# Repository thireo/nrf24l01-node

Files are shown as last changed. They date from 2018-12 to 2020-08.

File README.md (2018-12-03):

Indoor climate measuring nodes running on a single coin cell battery. Measurements done every 5 minutes (not necessarily sent at same interval).

Specs. for now:

* NRF24L01 - 2.4GHz module
* SAMD21G18 - MCU
* CR2450 - Coin cell battery ~ 500+mAh
* BME280 - Temperature, Humidity & Pressure.
* DS1302 - Ultra low power RTC for waking up node / Perhaps instead TLP5010.

Ideas to improve battery life:
Latch/flippydifloppy to control power to MCU + SIP32431.

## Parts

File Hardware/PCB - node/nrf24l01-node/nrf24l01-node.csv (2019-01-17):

Id | Designator | Package | Quantity | Designation | Supplier and ref
1 | REF**,REF** | MountingHole_4.3mm_M4---PASTY | 2 | MountingHole_4.3mm_M4---PASTY
2 | C19,C4,C18,C6,C7,C8,C9,C10,C11,C13,C15,C16,C17 | C_0603_1608Metric | 13 | 100nF
3 | IC4,IC3 | SC-70-6 | 2 | SIP32431
4 | R8 | R_0603_1608Metric | 1 | 1M
5 | R7,R4,R5,R6,R3 | R_0603_1608Metric | 5 | 100k
6 | BT1 | BatteryHolder_Keystone_3008_1x2450 | 1 | Coin Cell
7 | CON1 | HFW6R_2STE1LF | 1 | FPC_6POS
8 | L1 | C_0603_1608Metric | 1 | SMD-FERRITE-CHIP-120-OHM-500MA_0603_
9 | C3,C2 | C_0603_1608Metric | 2 | 15pF
10 | Y1 | Crystal_SMD_3215-2Pin_3.2x1.5mm | 1 | Crystal_Small
11 | C1 | SCMQ14C474PRBA0 | 1 | SuperCap
12 | C5 | C_0603_1608Metric | 1 | 100uF
13 | C12,C14 | C_0603_1608Metric | 2 | 10uF
14 | IC1 | TQFP-48_7x7mm_P0.5mm | 1 | ATSAMD21G18A-AU
15 | IC2 | SOT-23-6 | 1 | TLP5010
16 | R1 | R_0603_1608Metric | 1 | 54.9k
17 | R2 | R_0603_1608Metric | 1 | 196k
18 | U1 | nRF24L01_Breakout | 1 | NRF24L01_Breakout
19 | U2 | Bosch_LGA-8_2.5x2.5mm_P0.65mm_ClockwisePinNumbering | 1 | BME280

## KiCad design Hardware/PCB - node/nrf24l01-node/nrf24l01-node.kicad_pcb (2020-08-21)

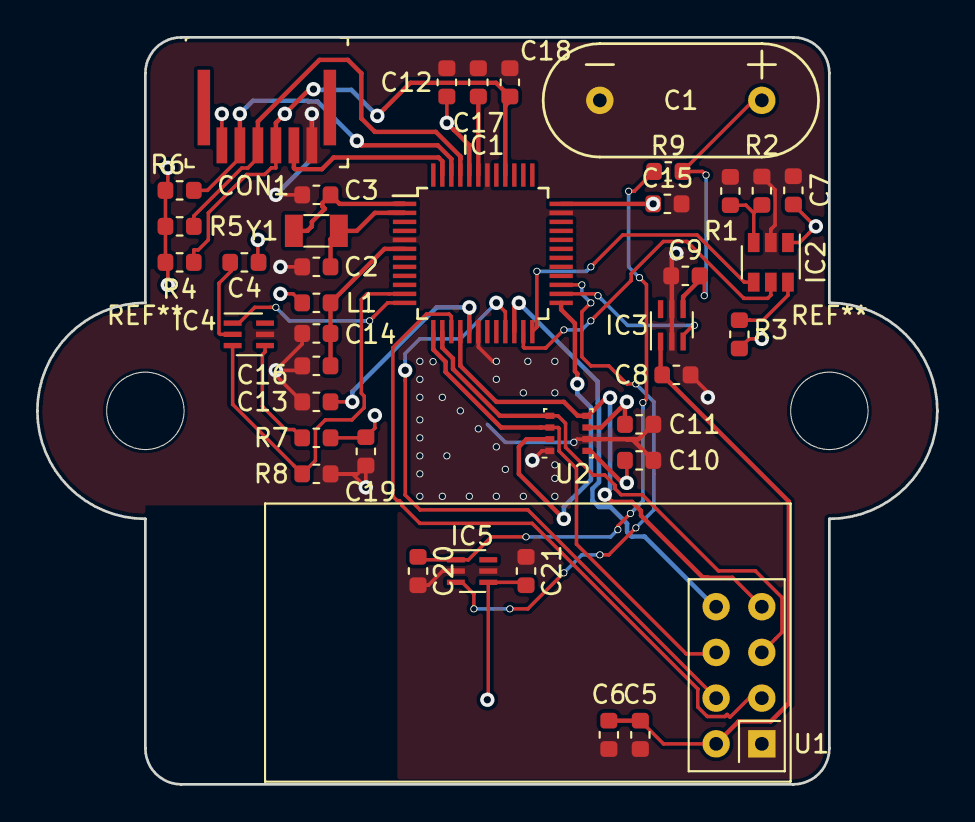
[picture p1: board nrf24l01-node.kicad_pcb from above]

Board: 2 copper layers, 50.0 x 41.5 mm, 41 parts (1 on the bottom side), 30 nets.

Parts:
BT1: Coin Cell; BatteryHolder_Keystone_3008_1x2450
C1: SuperCap; SCMQ14C474PRBA0
C2, C3: 15pF; C_0603_1608Metric
C4, C6, C7, C8, C9, C10, C11, C13, C15, C16, C17, C18, C19, C20, C21: 100nF; C_0603_1608Metric
C5: 100uF; C_0603_1608Metric
C12, C14: 10uF; C_0603_1608Metric
CON1: FPC_6POS; HFW6R_2STE1LF
IC1: ATSAMD21G18A-AU; TQFP-48_7x7mm_P0.5mm
IC2: TLP5010; SOT-23-6
IC3, IC4, IC5: SIP32431; SC-70-6
L1: SMD-FERRITE-CHIP-120-OHM-500MA_0603_; C_0603_1608Metric
R1: 54.9k; R_0603_1608Metric
R2: 196k; R_0603_1608Metric
R3, R4, R5, R6, R7: 100k; R_0603_1608Metric
R8: 1M; R_0603_1608Metric
R9: CAP_CHARGE_R; R_0603_1608Metric
U1: NRF24L01_Breakout; nRF24L01_Breakout
U2: BME280; Bosch_LGA-8_2.5x2.5mm_P0.65mm_ClockwisePinNumbering
Y1: Crystal_Small; Crystal_SMD_3215-2Pin_3.2x1.5mm

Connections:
/BME280_SCK: IC1.14, U1.5, U2.4
/BME280_SDI: IC1.13, U1.6, U2.3
/BME280_SDO: IC1.16, U1.7, U2.5
/BME280_SS: IC1.25, U2.2
/MCU_RESET: C18.2, CON1.4, IC1.40, R4.2
/NRF_CE: IC1.15, U1.3
/NRF_CS: IC1.21, U1.4
/NRF_IRQ: IC1.22, U1.8
/NRF_VCC_EN: IC1.26, IC3.3
/NRF_VCC_IN: C1.1, C9.2, IC3.4, R9.2
/NRF_VCC_OUT: C5.1, C6.1, C8.1, IC3.1, U1.2
/RESET_BTN: IC2.3, R1.1, R2.1
/SIG_DONE: IC1.24, IC2.4
/SIG_WAKE: IC1.23, IC2.5
/SUPER_CAP_EN: IC1.27, IC5.3
/SWCLK: CON1.3, IC1.45, R5.2
/SWDIO: CON1.2, IC1.46, R6.2
/UART_TX: CON1.5, IC1.47
/VBAT_ADC: IC1.12, IC4.1
/VBAT_ADC_EN: IC1.11, IC4.3, R8.2
/VDDANA: C14.1, C16.1, IC1.6, L1.2
/VDDCORE: C17.1, IC1.43
GND: BT1.2, C1.2, C2.2, C3.2, C5.2, C6.2, C7.2, C8.2, C9.1, C10.2, C11.2, C12.2, C13.2, C14.2, C15.2, C16.2, C17.2, C18.1, C19.2, C20.2, C21.1, CON1.6, IC1.5, IC1.18, IC1.35, IC1.42, IC2.2, IC3.2, IC3.5, IC4.5, IC5.2, IC5.5, R1.2, R2.2, R8.1, U1.1, U2.1, U2.7
unnamed: C2.1, IC1.2, Y1.2
unnamed: C3.1, IC1.1, Y1.1
unnamed: C4.2, IC4.2
unnamed: C20.1, IC5.1, R9.1
unnamed: IC2.6, R3.2
unnamed: IC4.4, R7.2
VCC: BT1.1, C4.1, C7.1, C10.1, C11.1, C12.1, C13.1, C15.1, C19.1, C21.2, CON1.1, IC1.17, IC1.36, IC1.44, IC2.1, IC5.4, L1.1, R3.1, R4.1, R5.1, R6.1, R7.1, U2.6, U2.8

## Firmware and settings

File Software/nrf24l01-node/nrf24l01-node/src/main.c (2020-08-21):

/**
 * \file
 *
 * \brief Empty user application template
 *
 */

/**
 * \mainpage User Application template doxygen documentation
 *
 * \par Empty user application template
 *
 * Bare minimum empty user application template
 *
 * \par Content
 *
 * -# Include the ASF header files (through asf.h)
 * -# Minimal main function that starts with a call to system_init()
 * -# "Insert application code here" comment
 *
 */

/*
 * Include header files for all drivers that have been imported from
 * Atmel Software Framework (ASF).
 */
/*
 * Support and FAQ: visit <a href="https://www.microchip.com/support/">Microchip Support</a>
 */
#include <asf.h>
#include "bme280.h"
#include "nrf24l01.h"
#include "uart.h"
#include "vbat.h"
#include "wakeup.h"


struct bme280_data bme280_data_object;
//char RX_ADDR[5] = {0x42,0x42,0x42,0x42,0};
//char TX_ADDR[5] = {0x2A,0x2A,0x2A,0x2A,0};

char TX_ADDR[5] = {0xe7,0xe7,0xe7,0xe7,0xe7};//{0xc2,0xc2,0xc2,0xc2,0xc2};
char RX_ADDR[5] = {0xe7,0xe7,0xe7,0xe7,0xe7};//;
	
uint8_t data_array[16];
char str_buf[64];

int main (void)
{
	system_init();
	delay_init();
	spi_master_init();
	uart_init();
	bme280_init();
	rotenc_init();
	sleepmgr_init();
	
	//vbat_init();
	nrf24l01_init();
	
	sprintf(str_buf,"\r\nBooting nrf24l01-node - app\r\n");
	uart_write(str_buf);
	sprintf(str_buf,"SW version: %d\r\n",SOFTWARE_VERSION);
	uart_write(str_buf);
	
	delay_ms(500);
	nrf24l01_status();
	
	woke = true;
	//uint16_t temp = vbat_read();
	//sleepmgr_enter_sleep();
	
	
	while (1)
	{
		if(woke)
		{
			nrf_enable_vcc();
			bme280_get_all_calced(&bme280_data_object);
			bme280_data_compress(&bme280_data_object,&data_array);
			//NRF_Enter_TX_Mode(TX_ADDR,RX_ADDR);
			uint32_t status = NRF_TX_data(&data_array,16);	
			nrf24l01_status();
			//uint32_t status = NRF_TX(NRF_CONTACT_2BTN_V1,NRF_CMD_OFF);
			uart_write("----------------\r\n");
			sprintf(str_buf,"T:\t%d\r\nH:\t%d\r\nP:\t%ld\r\n\r\n",bme280_data_object.temperature/100,(int)bme280_data_object.humidity,(int)bme280_data_object.pressure);
			uart_write(str_buf);
			woke = false;
			//sleepmgr_enter_sleep();
		}

		//uart_write("----------------\r\n");
		//temp = vbat_read();
		//float bob = temp/4096*2;
		//delay_ms(5000);
	}

	/* Insert application code here, after the board has been initialized. */
}

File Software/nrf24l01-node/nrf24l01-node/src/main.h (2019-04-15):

/*
 * main.h
 *
 * Created: 19-12-2017 17:46:26
 *  Author: Andreas
 */ 


#ifndef MAIN_H_
#define MAIN_H_

#include "asf.h"

#define SYSTEM_CLK 8000000


// defines for SAMD21
#define PORTGROUP_A		0
#define PORTGROUP_B		1

#define GPIO_SERCOM_ALT_D 3 //peripheral function D - SERCOM-ALT

#define GCM_SERCOM0_CORE          (0x14U)
#define GCM_SERCOM1_CORE          (0x15U)
#define GCM_SERCOM2_CORE          (0x16U)
#define GCM_SERCOM3_CORE          (0x17U)
#define GCM_SERCOM4_CORE          (0x18U)
#define GCM_SERCOM5_CORE          (0x19U)

#define SAMPLE_RATE_x16 0


#define SOFTWARE_VERSION 42


#define NRF_VCC_EN PIN_PA17
#define SIG_WAKE PIN_PA14
#define SIG_WAKE_MUX PINMUX_PA14A_EIC_EXTINT14
#define SIG_DONE_PIN PIN_PA15
#define SIG_DONE_MUX PINMUX_PA15A_EIC_EXTINT15
#define VBAT_ADC_PIN PIN_PA07
#define VBAT_ADC_PORT PORT_PA07
#define VBAT_ADC_EN_PIN PIN_PA06
#define VBAT_ADC_EN_PORT PORT_PA06

bool woke;

#endif /* MAIN_H_ */

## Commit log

2018-11-30 Current consumptions
    Added current consumption calculation sheet.
    [NRF24L01 current consumption.xlsx]
2018-12-03 Updated spreadsheet
    Current Consumption Excel file updated
    [NRF24L01 current consumption.xlsx]
2018-12-07 Did some Excel stuff
    Updated Excel sheet of current consumptions with more real values.
    Added "real" NRF24L01 times.
    Plan is to power off NRF24L01 in SLEEP period.
    [NRF24L01 current consumption.xlsx]
2018-12-07 Initial PCB commit
    [BME280.sch, MCUPWR.sch, USBUART.sch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]
2018-12-10 temp commit
    [BME280.sch, MCUPWR.sch, NRF24L01 current consumption.xlsx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]
2019-01-17 Initial Hardware commit
    [MCUPWR.sch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]
2019-01-17 Updated current consumption
    dunno changes specifically..
    [NRF24L01 current consumption.xlsx]
2019-04-15 Initial board bring SW - HW Rev. 2
    Functioning:
    BME280
    TPL5010
    UART
2020-08-21 Sorry future me
    [BME280.sch, MCUPWR.sch, NRF24L01 current consumption.xlsx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]
